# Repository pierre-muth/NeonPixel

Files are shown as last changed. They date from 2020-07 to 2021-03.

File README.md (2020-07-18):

# NeonPixel
Files about the NeonPixel Matrix, made of chainable 5V neon INS-1 bulbs

Detail here https://pierremuth.wordpress.com/2020/07/08/neon-pixel/

Youtube neonpixel video (https://www.youtube.com/watch?v=fUn0hQzyqzI)

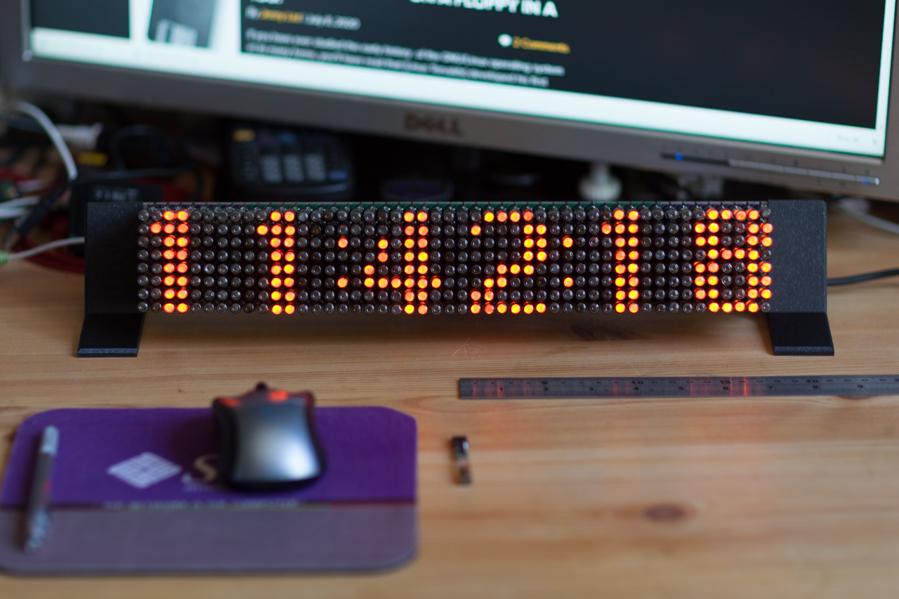
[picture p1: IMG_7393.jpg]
neonpixel01


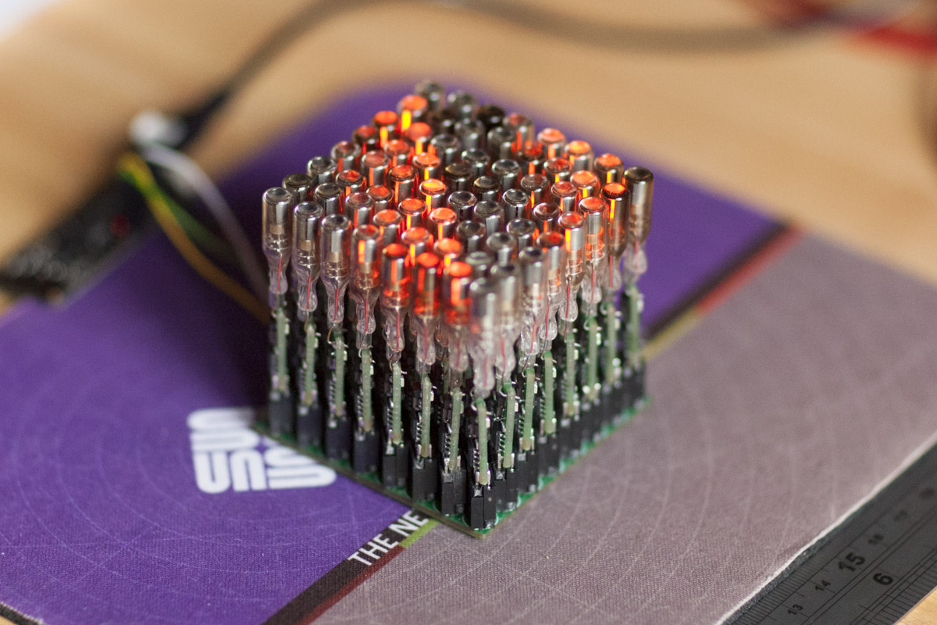
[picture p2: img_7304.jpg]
neonpixel02


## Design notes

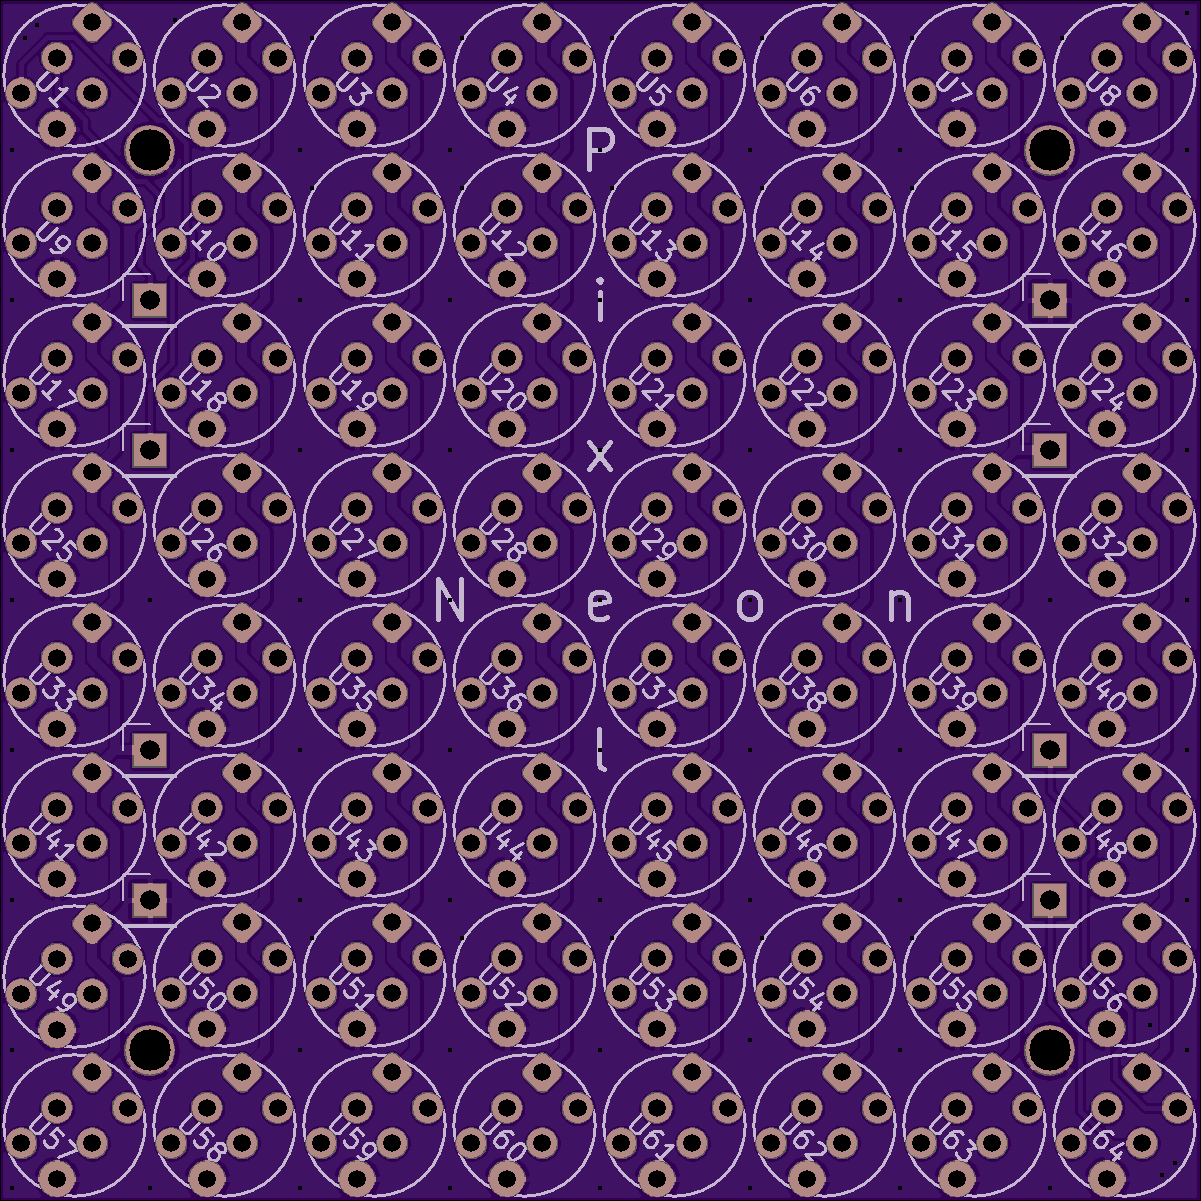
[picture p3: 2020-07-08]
kicad/neonpixelmatrix/3ad2aaec2b0d2028425cf52c3bd6bc67.png

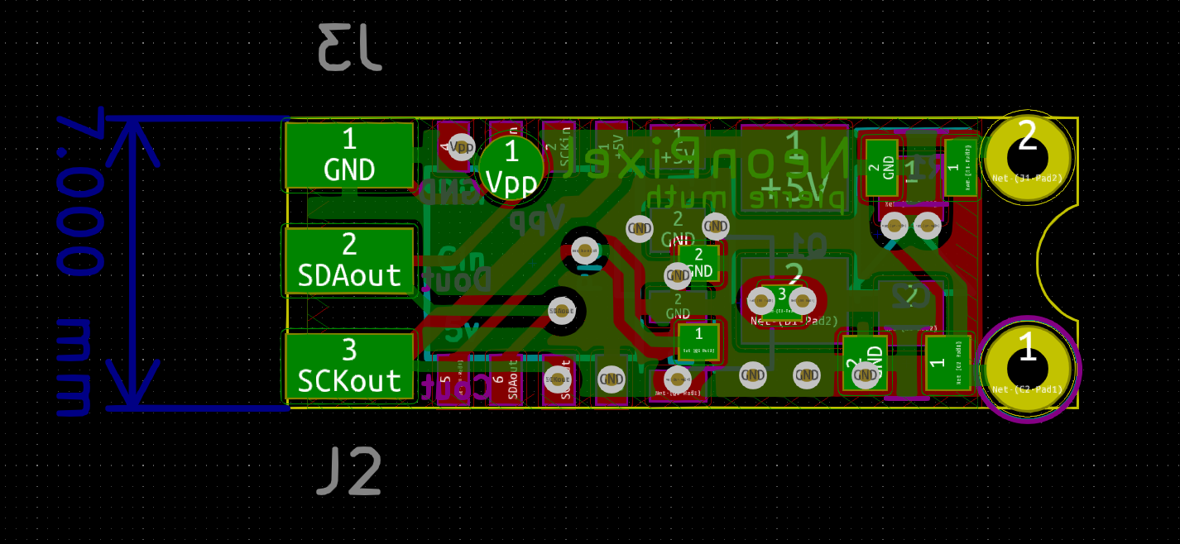
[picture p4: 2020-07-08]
kicad/neonpixel/NP_PCB.PNG

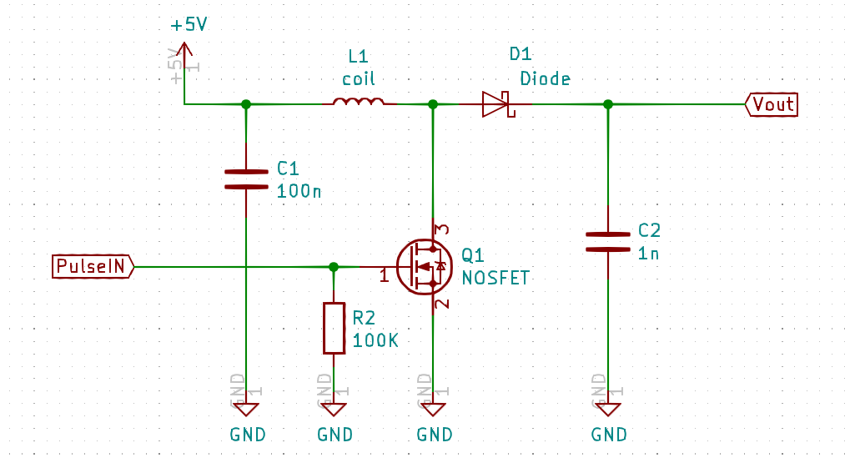
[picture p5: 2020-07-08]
kicad/neonpixel/Proto_SCH.PNG

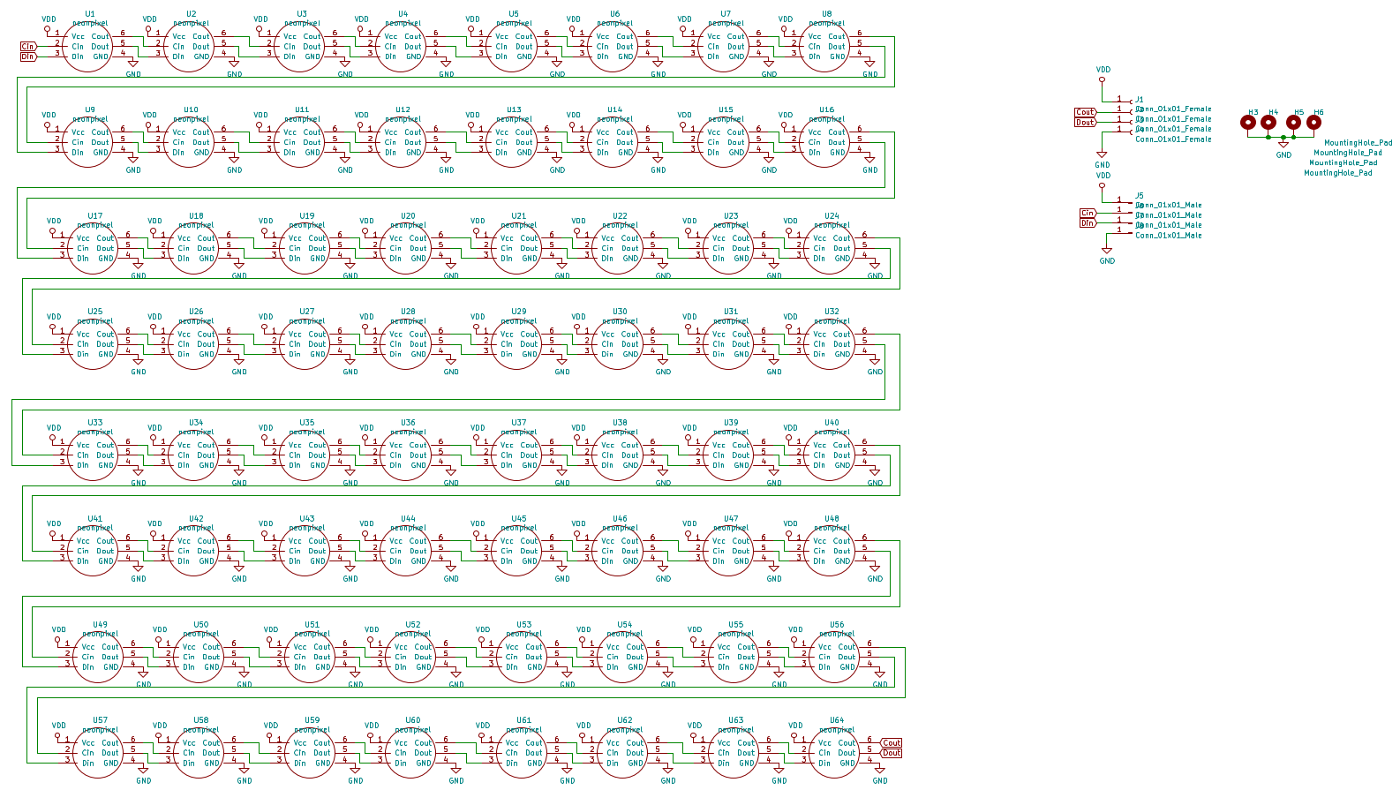
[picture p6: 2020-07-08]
kicad/neonpixelmatrix/NPM_SCH.PNG

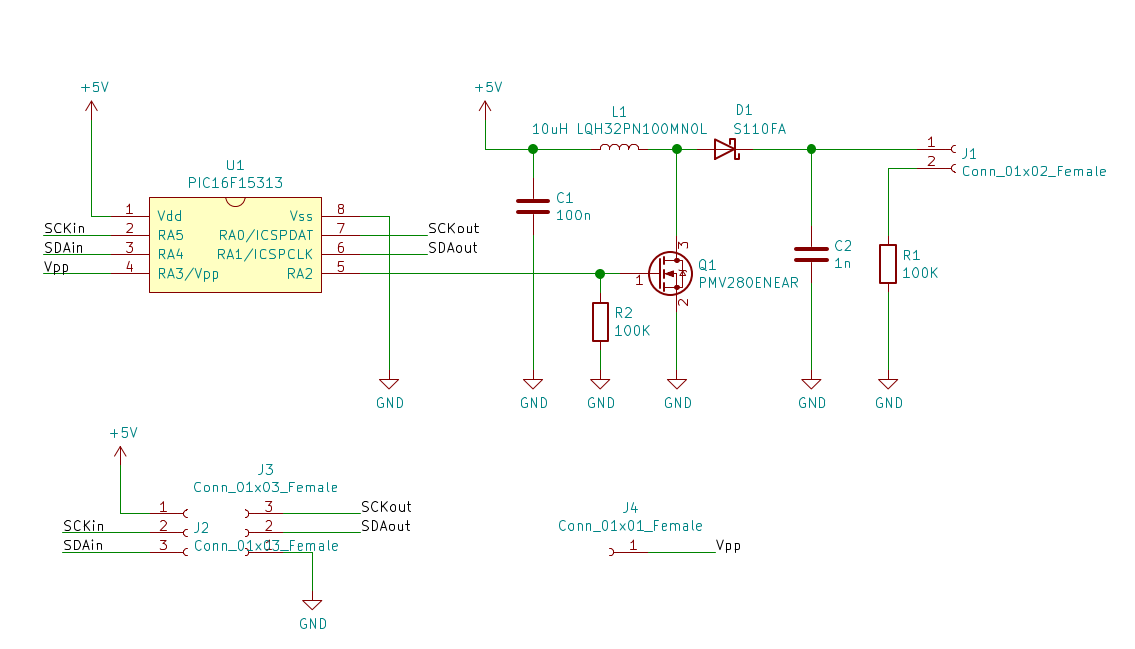
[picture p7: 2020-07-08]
kicad/neonpixel/NP_SCH.PNG

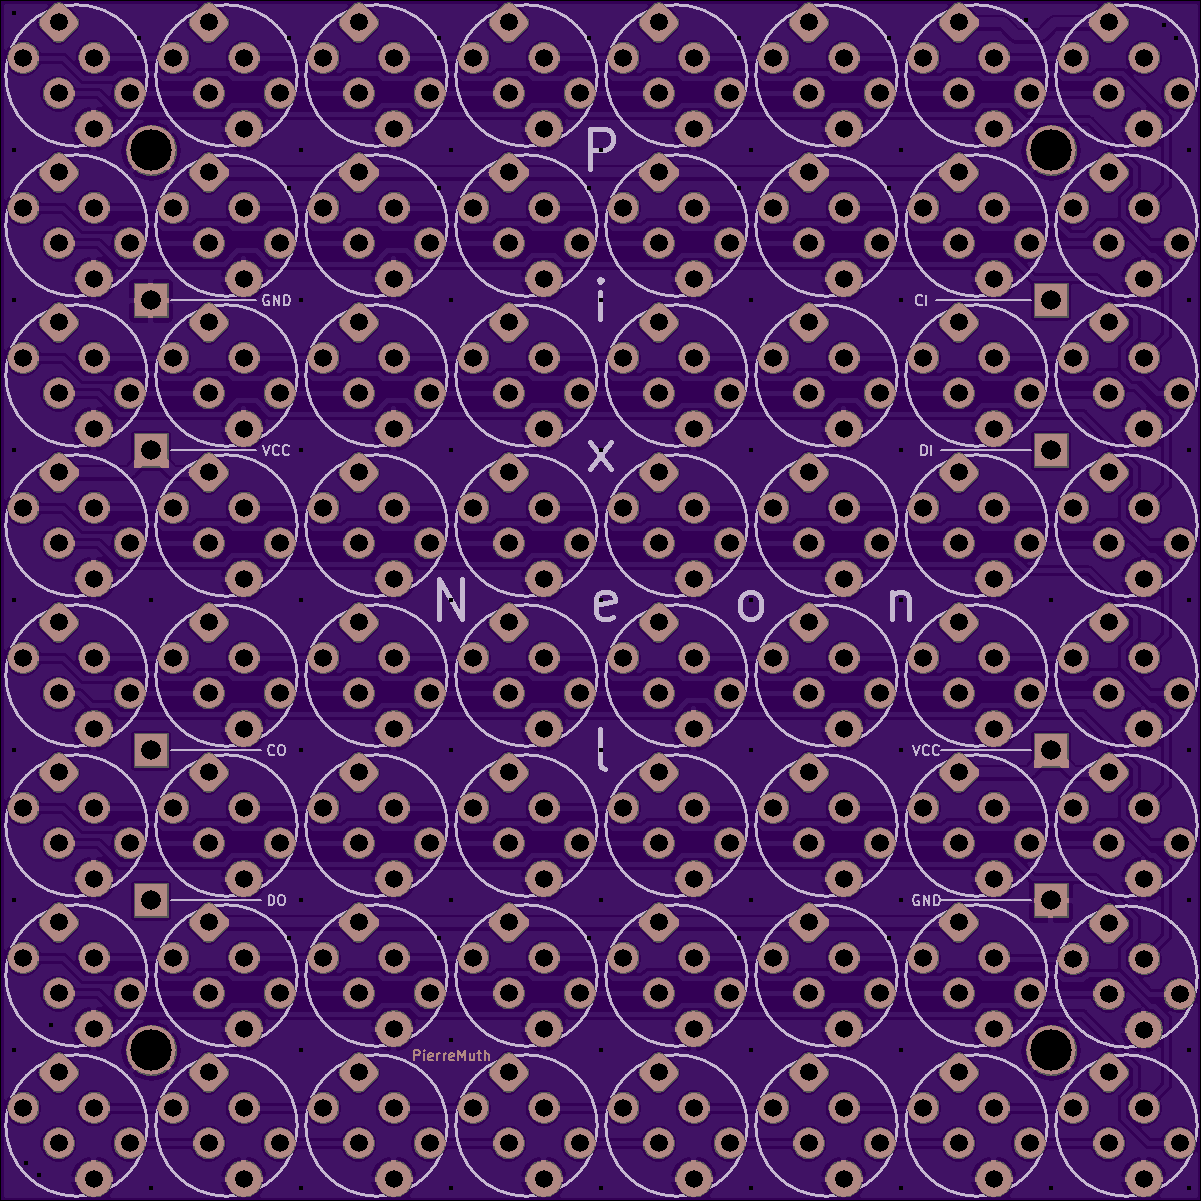
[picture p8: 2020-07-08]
kicad/neonpixelmatrix/aecb86608be49b999830e55a7333b157.png

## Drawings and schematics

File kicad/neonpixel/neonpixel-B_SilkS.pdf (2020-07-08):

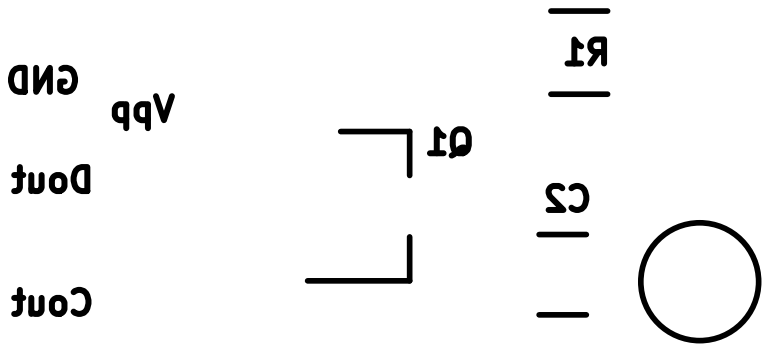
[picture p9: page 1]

Vpp Cout Dout GND

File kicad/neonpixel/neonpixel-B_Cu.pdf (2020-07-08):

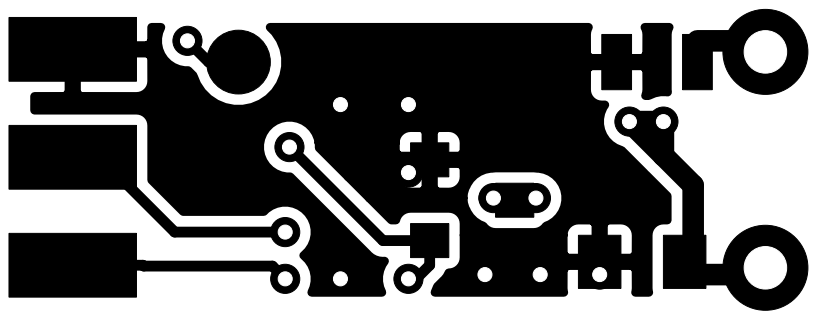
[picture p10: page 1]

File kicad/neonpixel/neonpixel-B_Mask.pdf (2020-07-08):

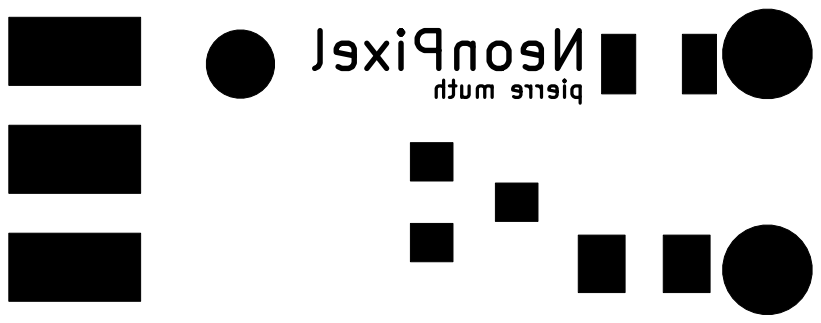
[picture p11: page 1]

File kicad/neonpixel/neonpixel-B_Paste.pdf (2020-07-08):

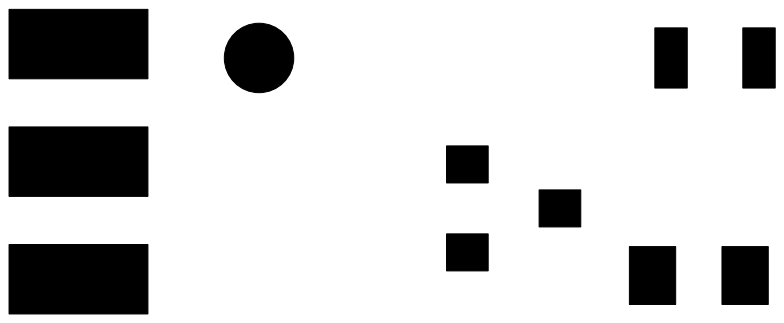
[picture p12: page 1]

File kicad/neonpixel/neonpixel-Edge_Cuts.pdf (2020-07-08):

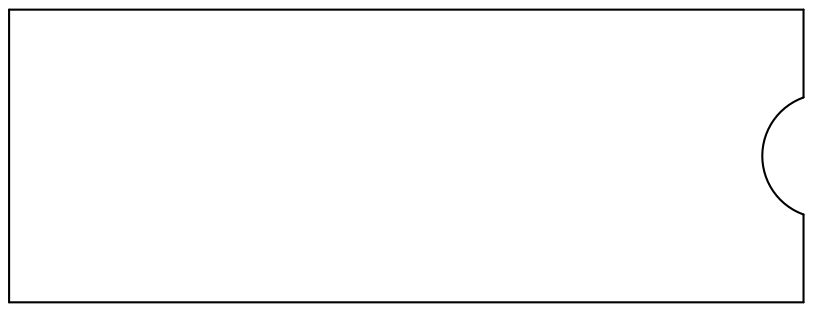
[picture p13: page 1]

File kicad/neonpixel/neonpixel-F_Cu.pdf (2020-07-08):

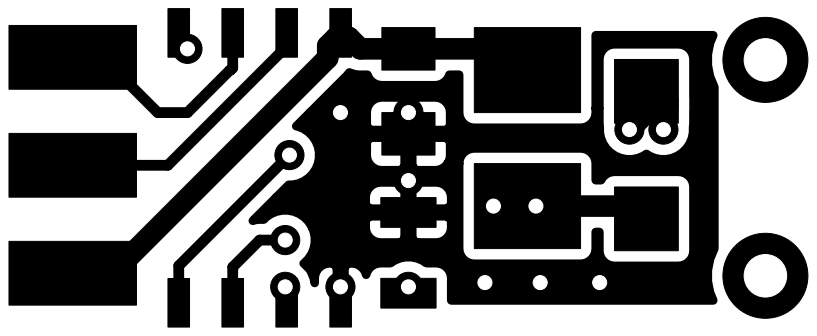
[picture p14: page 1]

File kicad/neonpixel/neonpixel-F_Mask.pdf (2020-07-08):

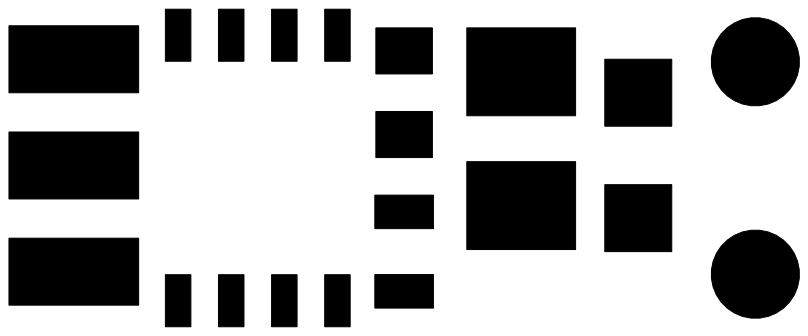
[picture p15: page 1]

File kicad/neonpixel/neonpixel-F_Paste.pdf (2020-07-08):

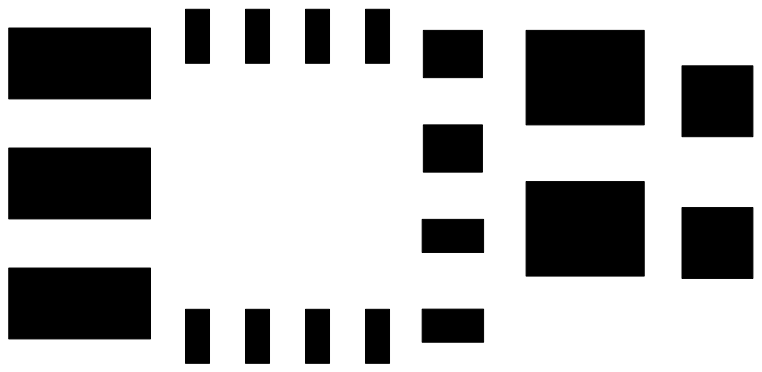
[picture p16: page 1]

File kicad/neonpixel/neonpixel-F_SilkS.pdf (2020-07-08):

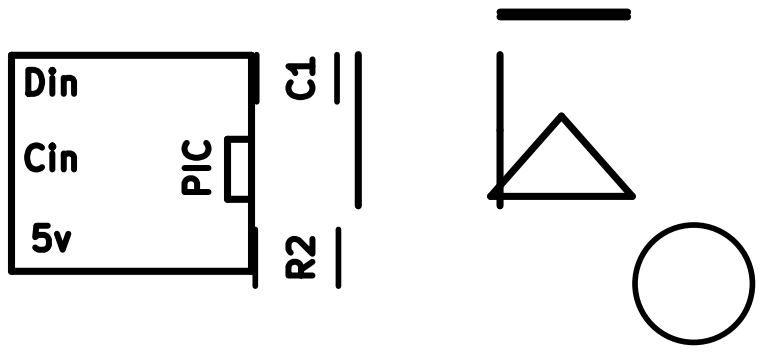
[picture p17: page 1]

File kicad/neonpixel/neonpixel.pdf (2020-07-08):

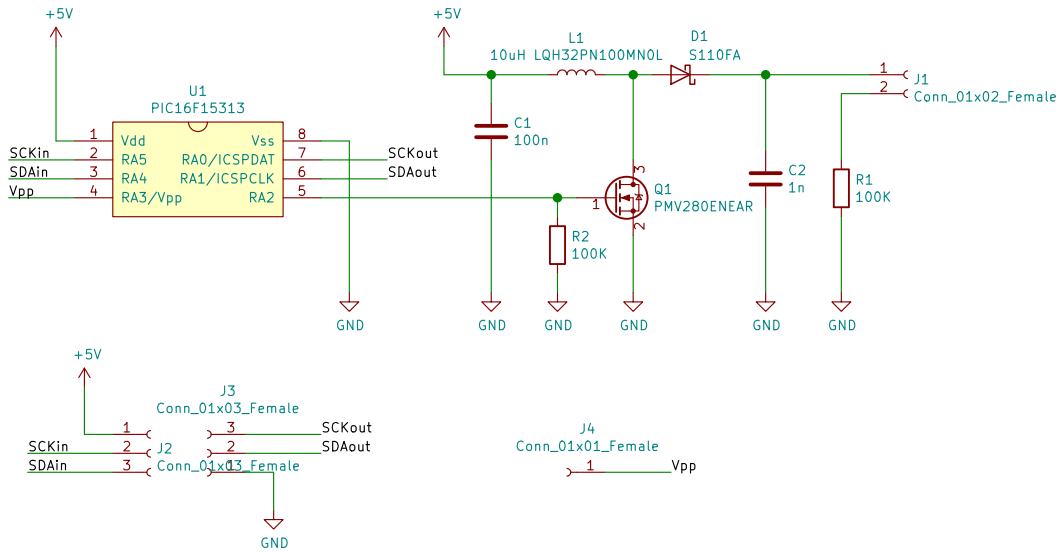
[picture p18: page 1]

File: neonpixel.sch Sheet: /
Id: 1/1 Title:

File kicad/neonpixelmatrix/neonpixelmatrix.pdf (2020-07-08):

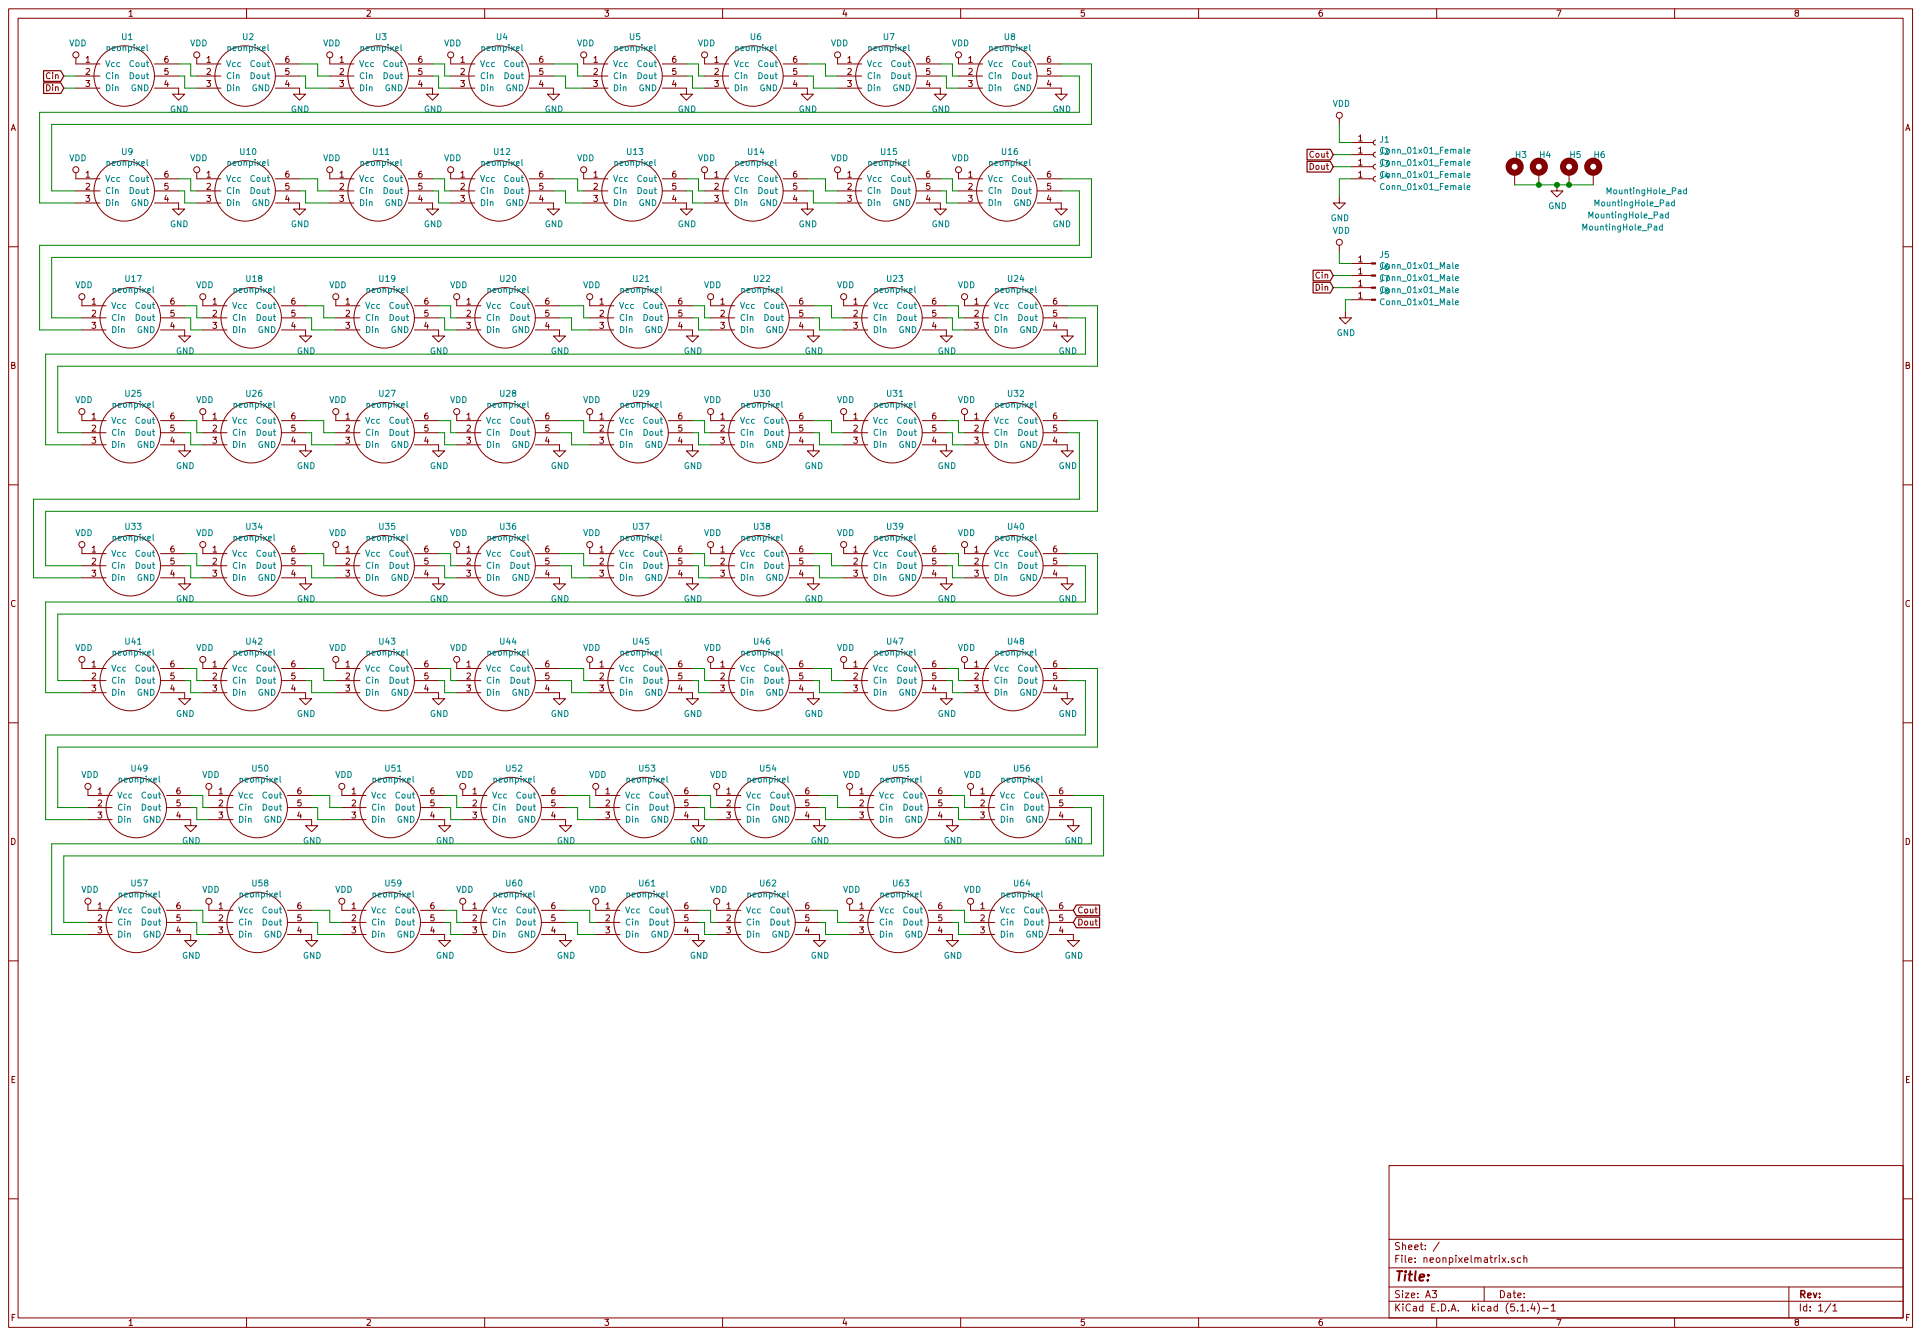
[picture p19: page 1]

Cout Dout Cin Cin Din

File: neonpixelmatrix.sch Sheet: /

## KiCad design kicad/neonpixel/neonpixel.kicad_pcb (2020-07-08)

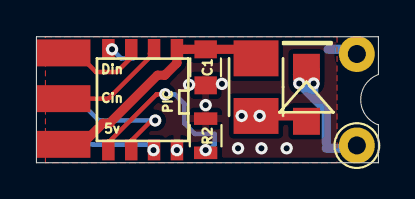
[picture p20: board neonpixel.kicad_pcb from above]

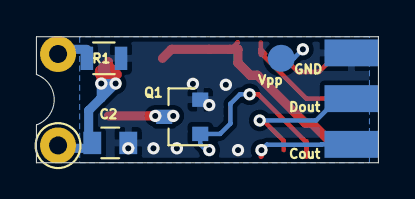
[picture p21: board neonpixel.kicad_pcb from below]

Board: 2 copper layers, 19.0 x 7.0 mm, 12 parts (5 on the bottom side), 11 nets.

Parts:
C1: 100n; C_0805
C2: 1n; C_0805
D1: D_Schottky; SMD_Diode
J1: Conn_01x02_Female; NeonPins
J2, J3: Conn_01x03_Female; SMD_3_pin_254
J4: Conn_01x01_Female; SMD_pad
L1: 10uH; SMD_inductor
PIC: PIC16F15313; SOIC-8-N
Q1: BSS138; SOT-23
R1: 10K; R_0805
R2: 100K; R_0805

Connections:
+5V: C1.1, J2.1, L1.1, PIC.1
/SCKin: J2.2, PIC.2
/SCKout: J3.3, PIC.7
/SDAin: J2.3, PIC.3
/SDAout: J3.2, PIC.6
/Vpp: J4.1, PIC.4
GND: C1.2, C2.2, J3.1, PIC.8, Q1.2, R1.2, R2.2
unnamed: C2.1, D1.1, J1.1
unnamed: D1.2, L1.2, Q1.3
unnamed: J1.2, R1.1
unnamed: PIC.5, Q1.1, R2.1

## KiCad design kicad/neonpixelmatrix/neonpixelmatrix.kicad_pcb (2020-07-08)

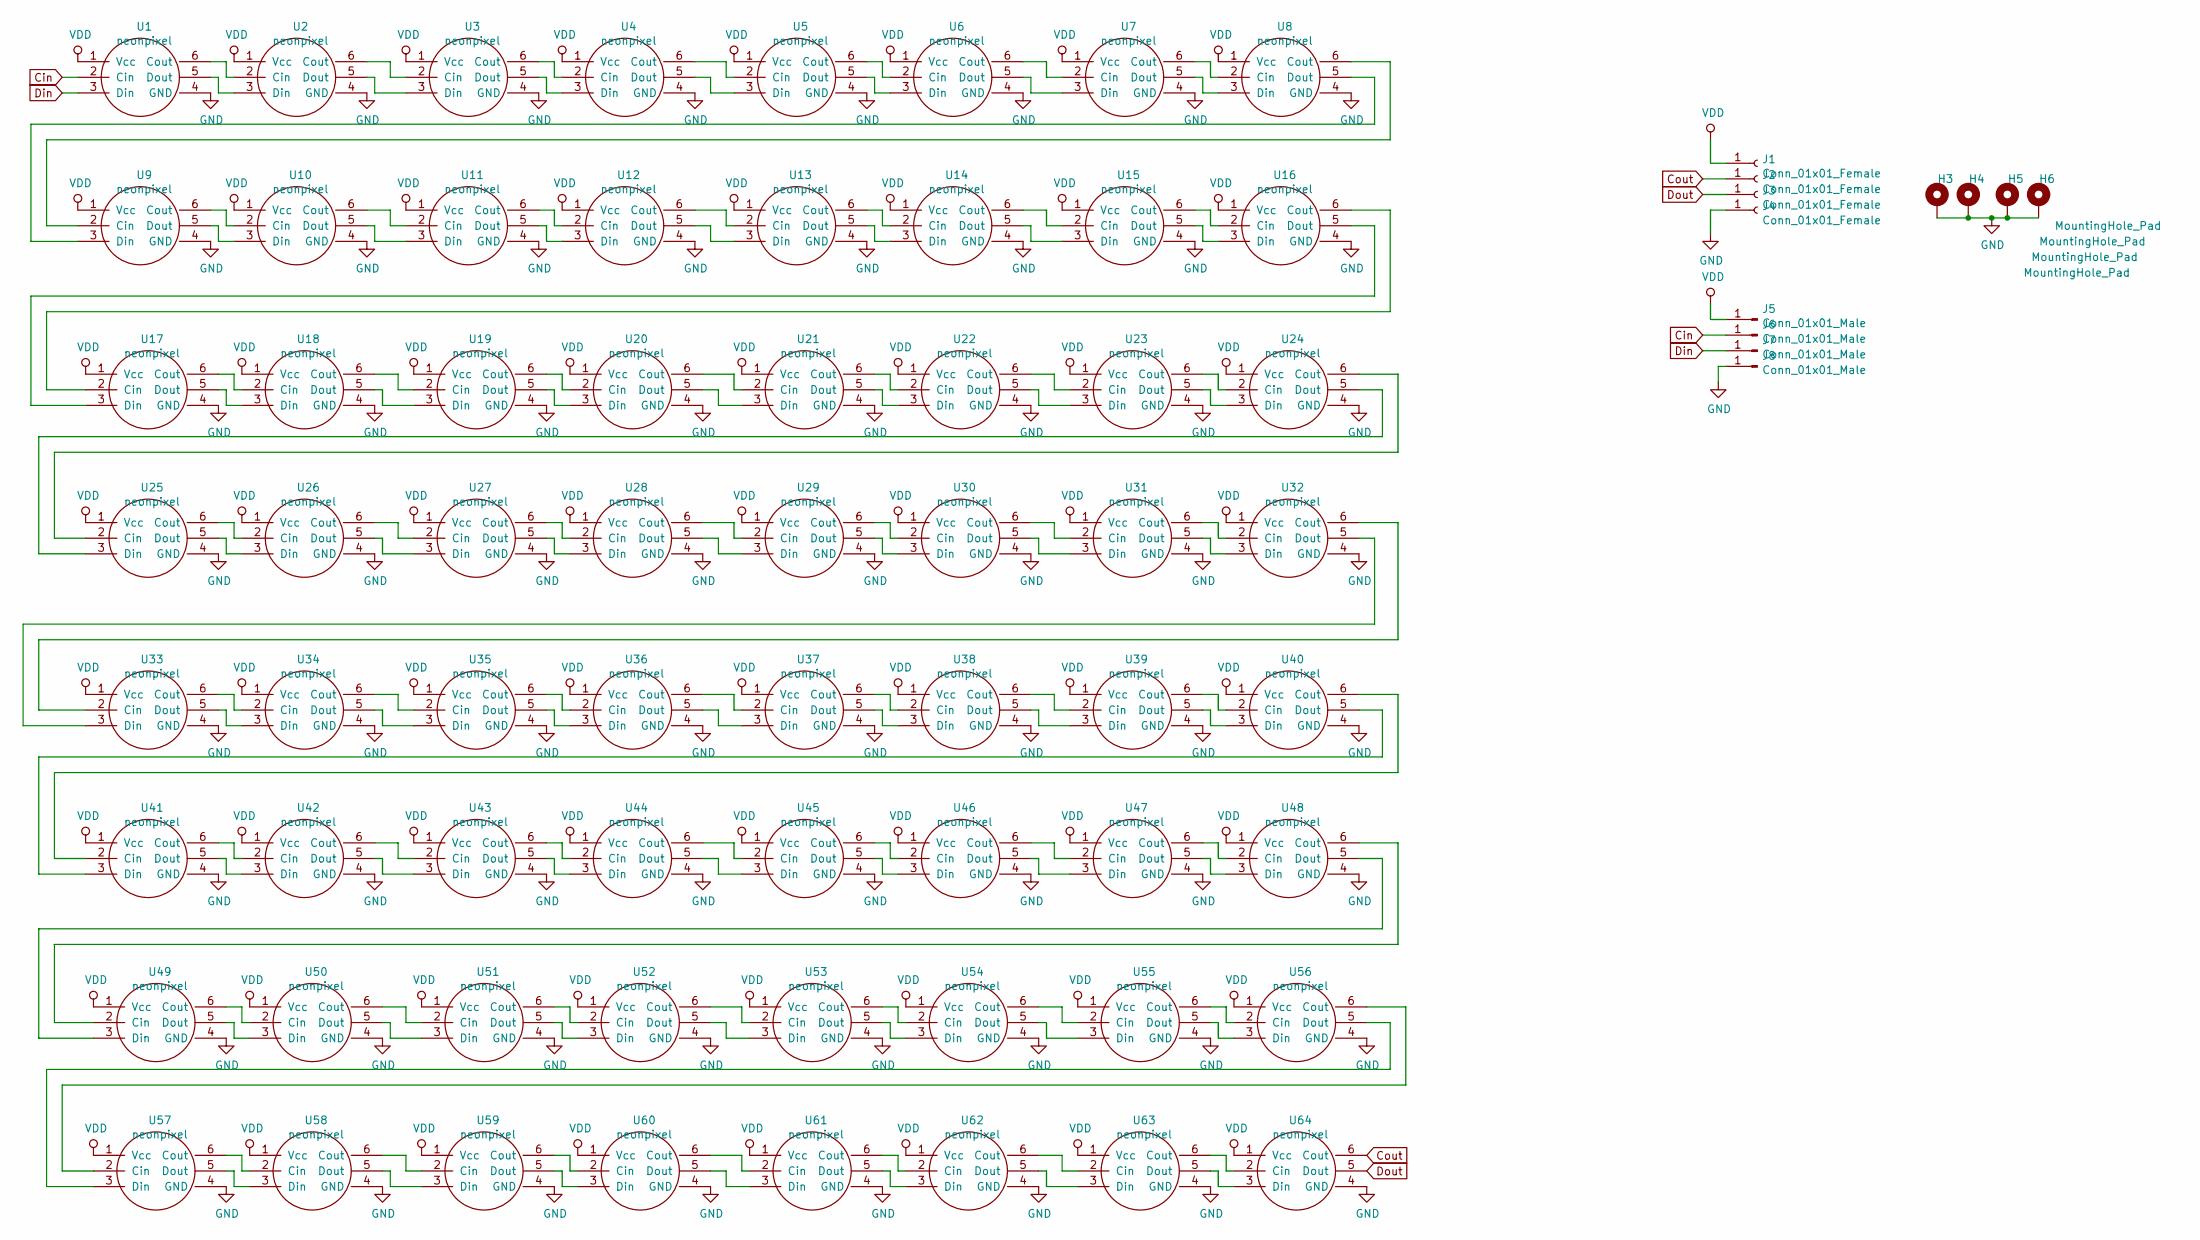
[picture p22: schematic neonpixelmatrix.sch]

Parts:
H3, H4, H5, H6: MountingHole_Pad; mountingM2
J1, J2, J3, J4: Conn_01x01_Female; Pin_Header_Straight_1x01_Pitch2.54mm
J5, J6, J7, J8: Conn_01x01_Male; Pin_Header_Straight_1x01_Pitch2.54mm
U1, U2, U3, U4, U5, U6, U7, U8, U9, U10, U11, U12, U13, U14, U15, U16, U17, U18, U19, U20, U21, U22, U23, U24, U25, U26, U27, U28, U29, U30, U31, U32, U33, U34, U35, U36, U37, U38, U39, U40, U41, U42, U43, U44, U45, U46, U47, U48, U49, U50, U51, U52, U53, U54, U55, U56, U57, U58, U59, U60, U61, U62, U63, U64: neonpixel

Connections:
Cin: J6.1, U1.2 (Cin)
Cout: J2.1, U64.6 (Cout)
Din: J7.1, U1.3 (Din)
Dout: J3.1, U64.5 (Dout)
GND: H3.1, H4.1, H5.1, H6.1, J4.1, J8.1, U1.4 (GND), U2.4 (GND), U3.4 (GND), U4.4 (GND), U5.4 (GND), U6.4 (GND), U7.4 (GND), U8.4 (GND), U9.4 (GND), U10.4 (GND), U11.4 (GND), U12.4 (GND), U13.4 (GND), U14.4 (GND), U15.4 (GND), U16.4 (GND), U17.4 (GND), U18.4 (GND), U19.4 (GND), U20.4 (GND), U21.4 (GND), U22.4 (GND), U23.4 (GND), U24.4 (GND), U25.4 (GND), U26.4 (GND), U27.4 (GND), U28.4 (GND), U29.4 (GND), U30.4 (GND), U31.4 (GND), U32.4 (GND), U33.4 (GND), U34.4 (GND), U35.4 (GND), U36.4 (GND), U37.4 (GND), U38.4 (GND), U39.4 (GND), U40.4 (GND), U41.4 (GND), U42.4 (GND), U43.4 (GND), U44.4 (GND), U45.4 (GND), U46.4 (GND), U47.4 (GND), U48.4 (GND), U49.4 (GND), U50.4 (GND), U51.4 (GND), U52.4 (GND), U53.4 (GND), U54.4 (GND), U55.4 (GND), U56.4 (GND), U57.4 (GND), U58.4 (GND), U59.4 (GND), U60.4 (GND), U61.4 (GND), U62.4 (GND), U63.4 (GND), U64.4 (GND)
unnamed: U1.5 (Dout), U2.3 (Din)
unnamed: U1.6 (Cout), U2.2 (Cin)
unnamed: U2.5 (Dout), U3.3 (Din)
unnamed: U2.6 (Cout), U3.2 (Cin)
unnamed: U3.5 (Dout), U4.3 (Din)
unnamed: U3.6 (Cout), U4.2 (Cin)
unnamed: U4.5 (Dout), U5.3 (Din)
unnamed: U4.6 (Cout), U5.2 (Cin)
unnamed: U5.5 (Dout), U6.3 (Din)
unnamed: U5.6 (Cout), U6.2 (Cin)
unnamed: U6.5 (Dout), U7.3 (Din)
unnamed: U6.6 (Cout), U7.2 (Cin)
unnamed: U7.5 (Dout), U8.3 (Din)
unnamed: U7.6 (Cout), U8.2 (Cin)
unnamed: U8.5 (Dout), U9.3 (Din)
unnamed: U8.6 (Cout), U9.2 (Cin)
unnamed: U9.6 (Cout), U10.2 (Cin)
unnamed: U9.5 (Dout), U10.3 (Din)
unnamed: U10.5 (Dout), U11.3 (Din)
unnamed: U10.6 (Cout), U11.2 (Cin)
unnamed: U11.5 (Dout), U12.3 (Din)
unnamed: U11.6 (Cout), U12.2 (Cin)
unnamed: U12.5 (Dout), U13.3 (Din)
unnamed: U12.6 (Cout), U13.2 (Cin)
unnamed: U13.5 (Dout), U14.3 (Din)
unnamed: U13.6 (Cout), U14.2 (Cin)
unnamed: U14.5 (Dout), U15.3 (Din)
unnamed: U14.6 (Cout), U15.2 (Cin)
unnamed: U15.5 (Dout), U16.3 (Din)
unnamed: U15.6 (Cout), U16.2 (Cin)
unnamed: U16.5 (Dout), U17.3 (Din)
unnamed: U16.6 (Cout), U17.2 (Cin)
unnamed: U17.5 (Dout), U18.3 (Din)
unnamed: U17.6 (Cout), U18.2 (Cin)
unnamed: U18.5 (Dout), U19.3 (Din)
unnamed: U18.6 (Cout), U19.2 (Cin)
unnamed: U19.5 (Dout), U20.3 (Din)
unnamed: U19.6 (Cout), U20.2 (Cin)
unnamed: U20.5 (Dout), U21.3 (Din)
unnamed: U20.6 (Cout), U21.2 (Cin)
unnamed: U21.5 (Dout), U22.3 (Din)
unnamed: U21.6 (Cout), U22.2 (Cin)
unnamed: U22.5 (Dout), U23.3 (Din)
unnamed: U22.6 (Cout), U23.2 (Cin)
unnamed: U23.5 (Dout), U24.3 (Din)
unnamed: U23.6 (Cout), U24.2 (Cin)
unnamed: U24.5 (Dout), U25.3 (Din)
unnamed: U24.6 (Cout), U25.2 (Cin)
unnamed: U25.5 (Dout), U26.3 (Din)
unnamed: U25.6 (Cout), U26.2 (Cin)
unnamed: U26.5 (Dout), U27.3 (Din)
unnamed: U26.6 (Cout), U27.2 (Cin)
unnamed: U27.5 (Dout), U28.3 (Din)
unnamed: U27.6 (Cout), U28.2 (Cin)
unnamed: U28.5 (Dout), U29.3 (Din)
unnamed: U28.6 (Cout), U29.2 (Cin)
unnamed: U29.5 (Dout), U30.3 (Din)
unnamed: U29.6 (Cout), U30.2 (Cin)
unnamed: U30.5 (Dout), U31.3 (Din)
unnamed: U30.6 (Cout), U31.2 (Cin)
unnamed: U31.5 (Dout), U32.3 (Din)
unnamed: U31.6 (Cout), U32.2 (Cin)
unnamed: U32.5 (Dout), U33.3 (Din)
unnamed: U32.6 (Cout), U33.2 (Cin)
unnamed: U33.5 (Dout), U34.3 (Din)
unnamed: U33.6 (Cout), U34.2 (Cin)
unnamed: U34.5 (Dout), U35.3 (Din)
unnamed: U34.6 (Cout), U35.2 (Cin)
unnamed: U35.5 (Dout), U36.3 (Din)
unnamed: U35.6 (Cout), U36.2 (Cin)
unnamed: U36.5 (Dout), U37.3 (Din)
unnamed: U36.6 (Cout), U37.2 (Cin)
unnamed: U37.5 (Dout), U38.3 (Din)
unnamed: U37.6 (Cout), U38.2 (Cin)
unnamed: U38.5 (Dout), U39.3 (Din)
unnamed: U38.6 (Cout), U39.2 (Cin)
unnamed: U39.5 (Dout), U40.3 (Din)
unnamed: U39.6 (Cout), U40.2 (Cin)
unnamed: U40.5 (Dout), U41.3 (Din)
unnamed: U40.6 (Cout), U41.2 (Cin)
unnamed: U41.5 (Dout), U42.3 (Din)
unnamed: U41.6 (Cout), U42.2 (Cin)
unnamed: U42.5 (Dout), U43.3 (Din)
unnamed: U42.6 (Cout), U43.2 (Cin)
unnamed: U43.5 (Dout), U44.3 (Din)
unnamed: U43.6 (Cout), U44.2 (Cin)
unnamed: U44.5 (Dout), U45.3 (Din)
unnamed: U44.6 (Cout), U45.2 (Cin)
unnamed: U45.5 (Dout), U46.3 (Din)
unnamed: U45.6 (Cout), U46.2 (Cin)
unnamed: U46.5 (Dout), U47.3 (Din)
unnamed: U46.6 (Cout), U47.2 (Cin)
unnamed: U47.5 (Dout), U48.3 (Din)
unnamed: U47.6 (Cout), U48.2 (Cin)
unnamed: U48.5 (Dout), U49.3 (Din)
unnamed: U48.6 (Cout), U49.2 (Cin)
unnamed: U49.5 (Dout), U50.3 (Din)
unnamed: U49.6 (Cout), U50.2 (Cin)
unnamed: U50.5 (Dout), U51.3 (Din)
unnamed: U50.6 (Cout), U51.2 (Cin)
unnamed: U51.5 (Dout), U52.3 (Din)
unnamed: U51.6 (Cout), U52.2 (Cin)
unnamed: U52.5 (Dout), U53.3 (Din)
unnamed: U52.6 (Cout), U53.2 (Cin)
unnamed: U53.5 (Dout), U54.3 (Din)
unnamed: U53.6 (Cout), U54.2 (Cin)
unnamed: U54.5 (Dout), U55.3 (Din)
unnamed: U54.6 (Cout), U55.2 (Cin)
unnamed: U55.5 (Dout), U56.3 (Din)
unnamed: U55.6 (Cout), U56.2 (Cin)
unnamed: U56.5 (Dout), U57.3 (Din)
unnamed: U56.6 (Cout), U57.2 (Cin)
unnamed: U57.5 (Dout), U58.3 (Din)
unnamed: U57.6 (Cout), U58.2 (Cin)
unnamed: U58.5 (Dout), U59.3 (Din)
unnamed: U58.6 (Cout), U59.2 (Cin)
unnamed: U59.5 (Dout), U60.3 (Din)
unnamed: U59.6 (Cout), U60.2 (Cin)
unnamed: U60.5 (Dout), U61.3 (Din)
unnamed: U60.6 (Cout), U61.2 (Cin)
unnamed: U61.5 (Dout), U62.3 (Din)
unnamed: U61.6 (Cout), U62.2 (Cin)
unnamed: U62.5 (Dout), U63.3 (Din)
unnamed: U62.6 (Cout), U63.2 (Cin)
unnamed: U63.5 (Dout), U64.3 (Din)
unnamed: U63.6 (Cout), U64.2 (Cin)
VDD: J1.1, J5.1, U1.1 (Vcc), U2.1 (Vcc), U3.1 (Vcc), U4.1 (Vcc), U5.1 (Vcc), U6.1 (Vcc), U7.1 (Vcc), U8.1 (Vcc), U9.1 (Vcc), U10.1 (Vcc), U11.1 (Vcc), U12.1 (Vcc), U13.1 (Vcc), U14.1 (Vcc), U15.1 (Vcc), U16.1 (Vcc), U17.1 (Vcc), U18.1 (Vcc), U19.1 (Vcc), U20.1 (Vcc), U21.1 (Vcc), U22.1 (Vcc), U23.1 (Vcc), U24.1 (Vcc), U25.1 (Vcc), U26.1 (Vcc), U27.1 (Vcc), U28.1 (Vcc), U29.1 (Vcc), U30.1 (Vcc), U31.1 (Vcc), U32.1 (Vcc), U33.1 (Vcc), U34.1 (Vcc), U35.1 (Vcc), U36.1 (Vcc), U37.1 (Vcc), U38.1 (Vcc), U39.1 (Vcc), U40.1 (Vcc), U41.1 (Vcc), U42.1 (Vcc), U43.1 (Vcc), U44.1 (Vcc), U45.1 (Vcc), U46.1 (Vcc), U47.1 (Vcc), U48.1 (Vcc), U49.1 (Vcc), U50.1 (Vcc), U51.1 (Vcc), U52.1 (Vcc), U53.1 (Vcc), U54.1 (Vcc), U55.1 (Vcc), U56.1 (Vcc), U57.1 (Vcc), U58.1 (Vcc), U59.1 (Vcc), U60.1 (Vcc), U61.1 (Vcc), U62.1 (Vcc), U63.1 (Vcc), U64.1 (Vcc)

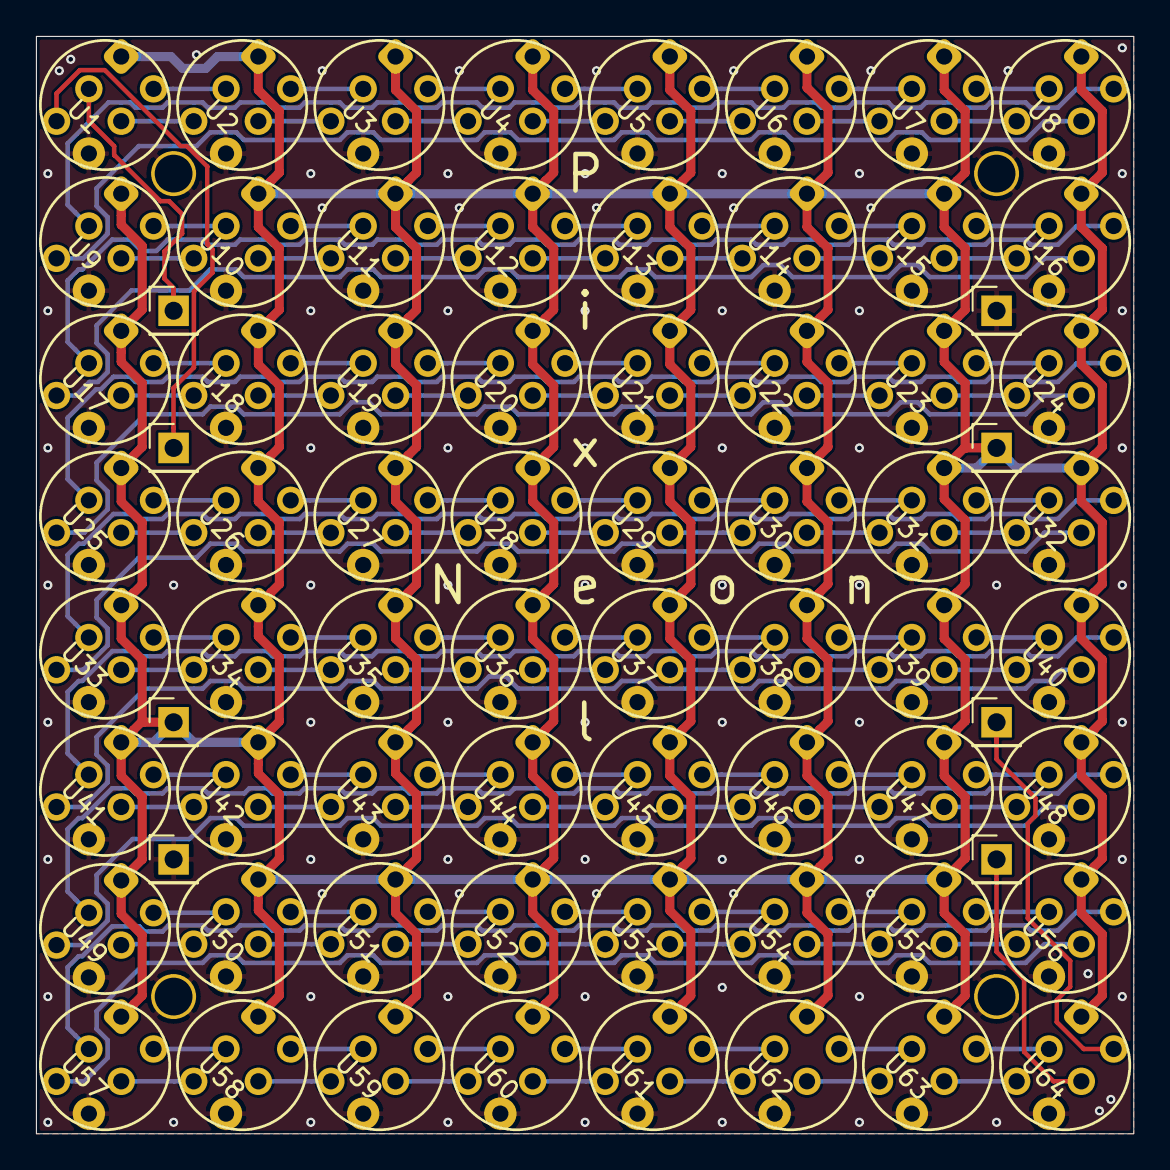
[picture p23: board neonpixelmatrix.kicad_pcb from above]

Board: 2 copper layers, 61.0 x 61.0 mm, 76 parts (0 on the bottom side), 132 nets.

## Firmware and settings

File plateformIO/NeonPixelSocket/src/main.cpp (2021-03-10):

#include <Arduino.h>
#include <SPI.h>
#include <WiFi.h>

#define DATAPIN    26
#define CLOCKPIN   27

const char* ssid = "xxx";
const char* password = "xxx";

static const int spiClk = 400000; 

SPIClass * hspi = NULL; //uninitalised pointers to SPI object

uint8_t *displayBuffer;

WiFiServer wifiServer(81);

void WiFiEvent(WiFiEvent_t event, WiFiEventInfo_t info) {
    switch (event) {

        case SYSTEM_EVENT_STA_START:
            WiFi.setHostname("FipDots");
            break;
        case SYSTEM_EVENT_STA_CONNECTED:
            Serial.println("STA connected");
            break;
        case SYSTEM_EVENT_STA_GOT_IP:
            Serial.println("STA got IP");
            Serial.print("STA SSID: ");
            Serial.println(WiFi.SSID());
            Serial.print("STA IPv4: ");
            Serial.println(WiFi.localIP());
            Serial.print("MAC address: ");
            Serial.println(WiFi.macAddress());

            wifiServer.begin();
            
            break;
        case SYSTEM_EVENT_STA_DISCONNECTED:
            Serial.print("STA Disconnected. ");
            Serial.println(info.disconnected.reason);
            WiFi.persistent(false);
            WiFi.disconnect(true);
            ESP.restart();
            break;
        default:
            break;
    }
}
void connectWiFi() {
    WiFi.persistent(false);
    WiFi.disconnect(true);
    WiFi.mode(WIFI_OFF);
    WiFi.mode(WIFI_STA);

    WiFi.onEvent(WiFiEvent);
    WiFi.begin(ssid, password);
    Serial.println(F("WiFi connexion ongoing"));
}

void setup() {

  hspi = new SPIClass(HSPI);
  hspi->begin(CLOCKPIN, 12, DATAPIN, 14); //SCLK, MISO, MOSI, SS

  displayBuffer = (uint8_t *)malloc(24 * 16);

  Serial.begin(115200);
  while (!Serial) { ; }
  delay(500); 

  connectWiFi();
  delay(1000);

  for(int i=0; i<384; i++){
    displayBuffer[i] = 0x01;
  }

  hspi->beginTransaction(SPISettings(spiClk, MSBFIRST, SPI_MODE0));
  hspi->transferBytes(displayBuffer , NULL, (24*16));
  hspi->endTransaction();

}

int count = 0;
int frameCount=0;

void loop() {

  WiFiClient client = wifiServer.available();
 
  if (client) {
 
    while (client.connected()) {
      while (client.available()>0) {
        char c = client.read();
        // Serial.print(c, HEX);
        // Serial.print(' ');
        displayBuffer[count] = c;
        count++;
        if (count>=384) {
          count = 0;
          Serial.println(frameCount++);
          
          hspi->beginTransaction(SPISettings(spiClk, MSBFIRST, SPI_MODE0));
          hspi->transferBytes(displayBuffer , NULL, (24*16));
          hspi->endTransaction();

          delay(15);
        } 
      }
 
      delay(15);
    }

    client.stop();
    Serial.println("\nClient disconnected\n");
    count = 0;
    frameCount = 0;
  }
  delay(1);

}

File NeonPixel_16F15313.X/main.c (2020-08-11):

/**
  Generated Main Source File

  Company:
    Microchip Technology Inc.

  File Name:
    main.c

  Summary:
    This is the main file generated using PIC10 / PIC12 / PIC16 / PIC18 MCUs

  Description:
    This header file provides implementations for driver APIs for all modules selected in the GUI.
    Generation Information :
        Product Revision  :  PIC10 / PIC12 / PIC16 / PIC18 MCUs - 1.80.0
        Device            :  PIC16F15313
        Driver Version    :  2.00
*/

/*
    (c) 2018 Microchip Technology Inc. and its subsidiaries. 
    
    Subject to your compliance with these terms, you may use Microchip software and any 
    derivatives exclusively with Microchip products. It is your responsibility to comply with third party 
    license terms applicable to your use of third party software (including open source software) that 
    may accompany Microchip software.
    
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
    IN NO EVENT WILL MICROCHIP BE LIABLE FOR ANY INDIRECT, SPECIAL, PUNITIVE, 
    INCIDENTAL OR CONSEQUENTIAL LOSS, DAMAGE, COST OR EXPENSE OF ANY KIND 
    WHATSOEVER RELATED TO THE SOFTWARE, HOWEVER CAUSED, EVEN IF MICROCHIP 
    HAS BEEN ADVISED OF THE POSSIBILITY OR THE DAMAGES ARE FORESEEABLE. TO 
    THE FULLEST EXTENT ALLOWED BY LAW, MICROCHIP'S TOTAL LIABILITY ON ALL 
    CLAIMS IN ANY WAY RELATED TO THIS SOFTWARE WILL NOT EXCEED THE AMOUNT 
    OF FEES, IF ANY, THAT YOU HAVE PAID DIRECTLY TO MICROCHIP FOR THIS 
    SOFTWARE.
*/

#include "mcc_generated_files/mcc.h"

uint8_t idleStart = 1;
uint16_t counter = 1;
uint8_t brightness = 0;

void spi1InterruptHandler(void) {
    idleStart = 0;
    brightness = SSP1BUF;
    TMR0L = 0x00;
    PIR3bits.SSP1IF = 0;
}

void tmr0InterruptHandler(void) {
    if (idleStart) {
        PWM3DCH = ((counter++)>>6)&0x7F;
    } else {
        PWM3DCH = brightness;
    }
    PIR0bits.TMR0IF = 0;
}

void main(void)
{
    // initialize the device
    
    SYSTEM_Initialize();

    // When using interrupts, you need to set the Global and Peripheral Interrupt Enable bits
    // Use the following macros to:

    // Enable the Global Interrupts
    INTERRUPT_GlobalInterruptEnable();

    // Enable the Peripheral Interrupts
    INTERRUPT_PeripheralInterruptEnable();

    // Disable the Global Interrupts
    //INTERRUPT_GlobalInterruptDisable();

    // Disable the Peripheral Interrupts
    //INTERRUPT_PeripheralInterruptDisable();
    
    SPI1_SetInterruptHandler(spi1InterruptHandler);
    SSP1CON1bits.SSPEN = 1;
    PWM3_LoadDutyValue(0); 
    TMR0_SetInterruptHandler(tmr0InterruptHandler);

    while (1){
        __delay_ms(50);
    }
}
/**
 End of File
*/

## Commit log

2021-03-10 upload socket screen connection ESP32 code
2021-03-10 Java code to stream video to ESP32 socket via wifi
